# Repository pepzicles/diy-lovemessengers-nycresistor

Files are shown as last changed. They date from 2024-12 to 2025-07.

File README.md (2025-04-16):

# 💖 Welcome to our Love Messengers Page, NYC Resistor edition

demo

by Julia Daser and Pepi Ng
<br>
<br>
👯‍♀️ This workshop is a community effort - thank you to all the lovely people that have supported the project, 
participated in our workshops, provided valuable feedback, and helped host us. 
<br>
<br>
🥰 Special thanks go out to Kari Love, Woody and NYC Resistor, Jonah and Katherine and Siggraph, Grace Park and Aiyo Cheboi!
<br>

## Access all of your workshop materials here:
### [December 2024 Workshop](./Dec%202024)
### [February 2025 Workshop](./Feb%202025)

<br>

## Contact us
We hope you guys had tons of fun building  DIY Love Messengers<br>
If you run into any issues, please reach out to us!! We would love to help
<br>
#### Email:  yiqing.ng@gmail.com
#### Instagram: [@julia.daser](https://www.instagram.com/julia.daser/)
#### Youtube: [@WormiCollective](https://www.youtube.com/@WormiCollective)

<br>

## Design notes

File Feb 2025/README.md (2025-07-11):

# February 2025 Edition of NYC Resistor Workshop!
**Sunday, Feb 9th and 14th, 2025** 
## About 
Our DIY Love Messengers are the perfect gift for your friends/ partners, especially long-distance ones! When the button of one love messenger is pressed, both of them will light up - no matter HOW FAR AWAY the two messengers are! We will be using all the files, code and 3D models from this repository.
<br>
<br>
demo
<br>
<br>
<br>
by Julia Daser and Pepi Ng
<br>
<br>
Thank you Aiyo Cheboi for your help in prep work 💖
Thank you Grace Park for the graphic design 💖
<br>

## This Github Page Contains
1. [**3D models**](./3D%20Models) of the box encasing, the floor, and the hearts for 3D-printing
2. The [**Code**](./code.ino) for the ESP8266 Microcontrollers
3. The [**Class-Slides**](https://docs.google.com/presentation/d/1ocXh6diw_edAS3Q-rFSFNbqER26dfUnC6ZojbTQyBRY/edit?usp=sharing)
4. The Slides on [**How to Create a Database**](https://docs.google.com/presentation/d/19Xh5I5hXMwRNAT6mXwnOo7upIBXxUXw2HIQn1awf7jE/edit?usp=sharing)
5. The Slides on [**How to Upload the ESP8266 Code**](https://docs.google.com/presentation/d/1gHVXxIc9Vdh47K_fa2g4CjRUR9ceTofEAE9G6XgcR_w/edit?usp=sharing)

<br>

## You attended our  workshop and want to use the Love Messengers at home?
To use the *Love Messengers* at home, you need to re-upload the code with your own WiFi name and Password. 
Follow our instructions if you need a reminder on how to do so: [Instructions](https://docs.google.com/presentation/d/1gHVXxIc9Vdh47K_fa2g4CjRUR9ceTofEAE9G6XgcR_w/edit?usp=sharing)
<br>
<br>
You can keep using the same Database we created in the workshop. (If you want to create a new Database, or you have not created one yet, follow [this tutorial](https://docs.google.com/presentation/d/19Xh5I5hXMwRNAT6mXwnOo7upIBXxUXw2HIQn1awf7jE/edit?usp=sharing).

<br>

## Contact us
We hope you guys had tons of fun building  DIY Love Messengers 💙🧡  <br>
If you run into any issues, please reach out to us!! We would love to help
<br>
#### Email:  yiqing.ng@gmail.com
#### Instagram: [@julia.daser](https://www.instagram.com/julia.daser/)
#### Youtube: [@WormiCollective](https://www.youtube.com/@WormiCollective)

<br>
<br>

## Materials needed to build two Love Messengers
1. 4x 3D-printed translucent heart **halves** (see '3D models' folder)
2. 2x 3D-printed box encasings (see '3D models' folder)
3. 2x 3D-printed box floors (see '3D models' folder)
4. 2x [16mm pre-soldered illuminated push buttons](https://www.aliexpress.us/item/3256807351535133.html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) (Make sure to purchase 'momentary' and '4-pin' option) ($0.90 per)
5. 2x [pre-soldered LEDs](https://www.amazon.com/Assorted-Transparent-Warm-White-Emitting-Assortment/dp/B08G4VKN1W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) (Pre-soldered with resistors, different colors are available and all function the same) ($0.35 per)
6. 4x [M2.5 x 10 mm Screws](https://www.amazon.com/uxcell-100pcs-Stainless-Phillips-Tapping/dp/B01KXTUCM8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)
7. 2x [ESP32-WROOM-32 microcontrollers, unassembled.](https://www.amazon.com/dp/B0BHW1CNCM?smid=A2Z10KY0342329&ref_=chk_typ_imgToDp&th=1) (We used ones with USBC ports.) ($3.30 per)
8. 2x [USBC wires](https://www.amazon.com/dp/B0CFQ5T5F6?ref=ppx_yo2ov_dt_b_fed_asin_title&th=1) (To upload code to microcontrollers, your USB wire needs to be able to both *charge* and *transmit data*.) ($2.00 per)

<br>   
<br>

## Wire Diagram: 
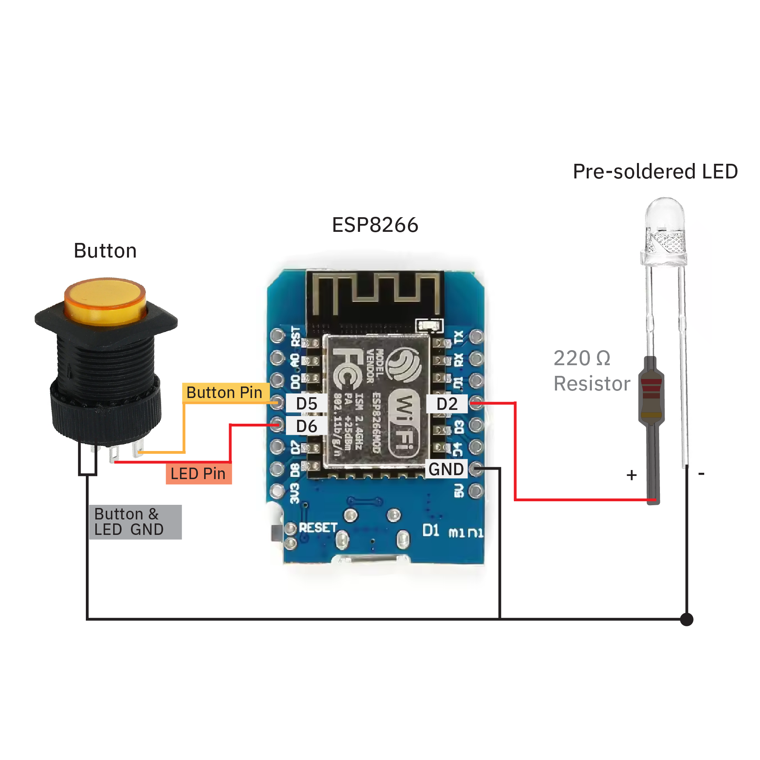
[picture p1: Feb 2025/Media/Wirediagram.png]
demo


<br>   
<br>

## Other Tools/ Equipment: 
1. Pliers
2. Wire Stripper
3. Small Screwdrivers
4. Soldering Kit

<br>
<br>

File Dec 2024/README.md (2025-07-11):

# December 2024 Edition NYC Resistor Workshop!
**Saturday, Dec 21, 2024** 
<br>
by Julia Daser and Pepi Ng
<br>

## This Github Page Contains
1. [**3D models**](./3D%20Models) of the box encasing, the floor, and the hearts for 3D-printing
2. The [**Code**](./code.ino) for the ESP32 Microcontrollers
3. The [**Class-Slides**](https://docs.google.com/presentation/d/1tKyRhq-H0f7qh0r20IBgMoWx7r3AGBdcS3LCC1Dzuw8/edit?usp=sharing)
4. The Slides on [**How to Create a Database**](https://docs.google.com/presentation/d/19Xh5I5hXMwRNAT6mXwnOo7upIBXxUXw2HIQn1awf7jE/edit?usp=sharing)
5. The Slides on [**How to Upload the ESP32 Code**](https://docs.google.com/presentation/d/10jpJMJF2ff4qg-6BC0tEkhLmOqasLfKd7yKnnkN3o50/edit?usp=sharing)

<br>

## You attended our  workshop and want to use the Love Messengers at home?
To use the *Love Messengers* at home, you need to re-upload the code with your own WiFi name and Password. 
Follow our PDF-instructions if you need a reminder on how to do so: [PDF Instructions](ADD URL HERE)
<br>
<br>
You can keep using the same Database we created in the workshop. (If you want to create a new Database, or you have not created one yet, follow [this tutorial](https://docs.google.com/presentation/d/19Xh5I5hXMwRNAT6mXwnOo7upIBXxUXw2HIQn1awf7jE/edit?usp=sharing).

<br>

## Contact us
We hope you guys had tons of fun building  DIY Love Messengers 💙🧡  <br>
If you run into any issues, please reach out to us!! We would love to help
<br>
#### Email:  yiqing.ng@gmail.com
#### Instagram: [@julia.daser](https://www.instagram.com/julia.daser/)
#### Youtube: [@WormiCollective](https://www.youtube.com/@WormiCollective)

<br>

## About 
Our DIY Love Messengers are the perfect gift for your friends/ partners, especially long-distance ones! When the button of one love messenger is pressed, both of them will light up - no matter HOW FAR AWAY the two messengers are! We will be using all the files, code and 3D models from this repository.
<br>
<br>
demo
<br>
<br>

## Materials needed to build two Love Messengers
1. 4x 3D-printed translucent heart OR star **halves** (see '3D models' folder)
2. 2x 3D-printed box encasings (see '3D models' folder)
3. 2x 3D-printed box floors (see '3D models' folder)
4. 2x [16mm pre-soldered illuminated push buttons](https://www.amazon.com/Momentary-Button-Switch-Assorted-Self-Resetting/dp/B08SKJ6V7Z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) ($0.62 per)
5. 2x [pre-soldered Super bright LEDs](https://www.amazon.com/dp/B01AUI4VQU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) (Pre-soldered with resistors) ($5.99 for 100)
6. 4x [M2.5 x 10 mm Screws](https://www.amazon.com/uxcell-100pcs-Stainless-Phillips-Tapping/dp/B01KXTUCM8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)
7. 2x [ESP32-WROOM-32 microcontrollers, unassembled. We used ones with USBC ports.](https://www.amazon.com/dp/B0B18NK2MS?ref=ppx_yo2ov_dt_b_fed_asin_title&th=1) ($5.40 per)
8. 2x [USBC wires](https://www.amazon.com/dp/B0CFQ5T5F6?ref=ppx_yo2ov_dt_b_fed_asin_title) (To upload code to microcontrollers, your USB wire needs to be able to both *charge* and *transmit data*.)

<br>   
<br>

## Wire Diagram: 
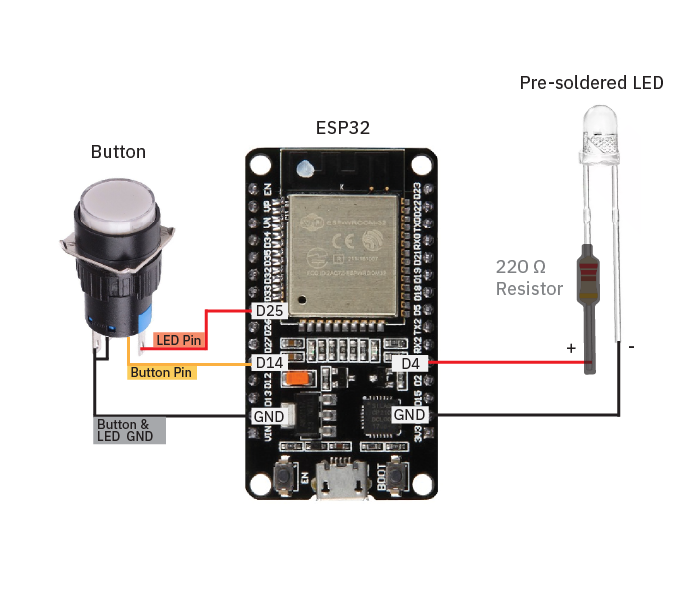
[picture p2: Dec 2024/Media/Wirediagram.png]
demo


<br>   
<br>

## Other Tools/ Equipment: 
1. Pliers
2. Wire Stripper
3. Small Screwdrivers
4. Soldering Kit

<br>
<br>

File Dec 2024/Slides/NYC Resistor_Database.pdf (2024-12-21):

## Creating the Real Time Database

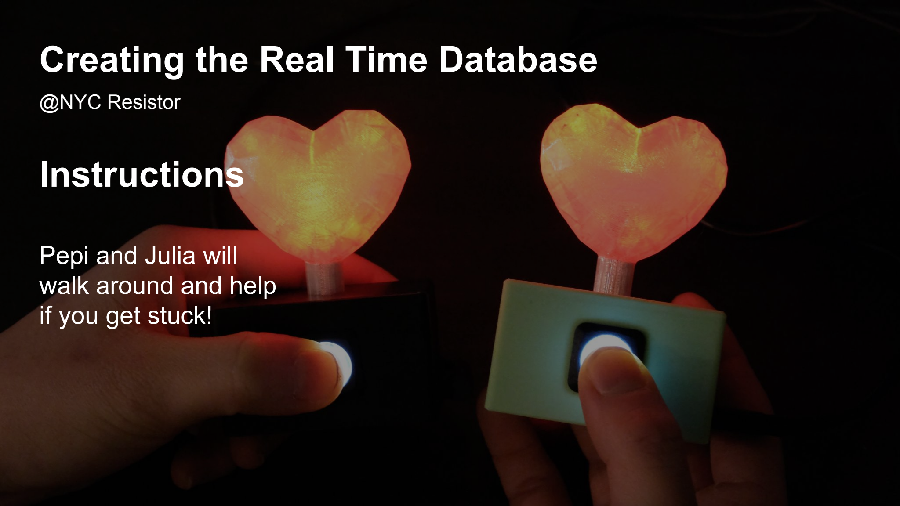
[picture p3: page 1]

@NYC Resistor

Pepi and Julia will
walk around and help
if you get stuck!

## Instructions

Step 1: Open console.firebase.google.com in Google Chrome, and log into your personal Google account.

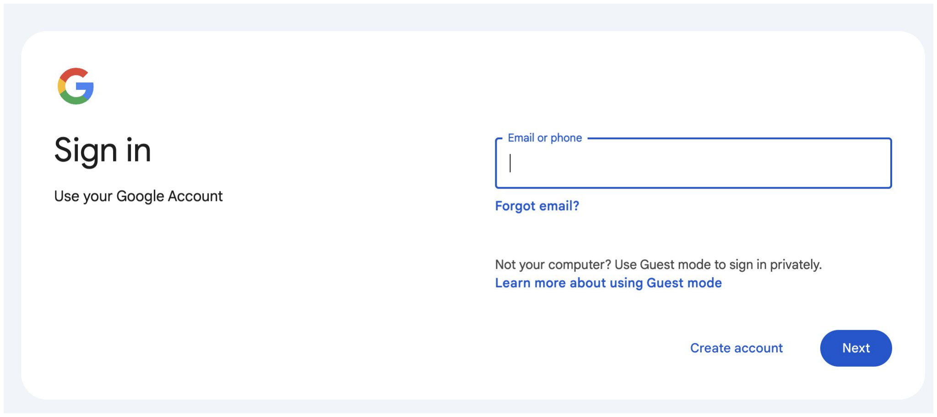
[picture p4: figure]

Step 2: In the Firebase website, select ”Get started with a Firebase project”

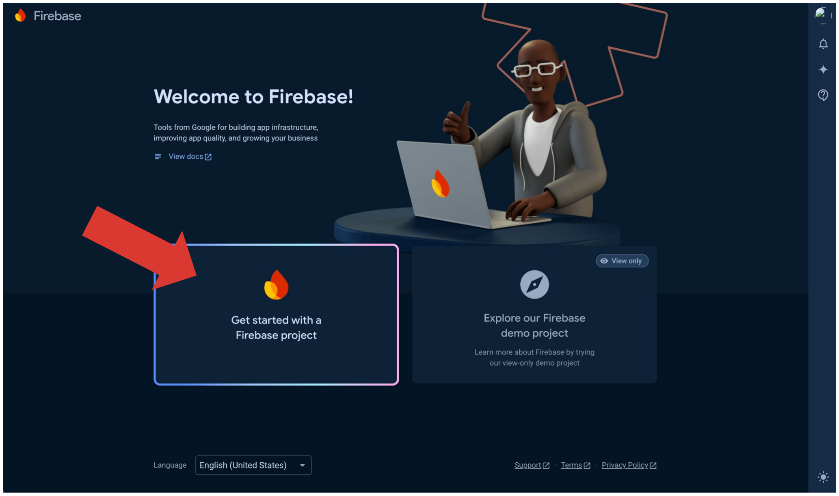
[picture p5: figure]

Step 3: Give your project a name, and hit the “Continue” button.

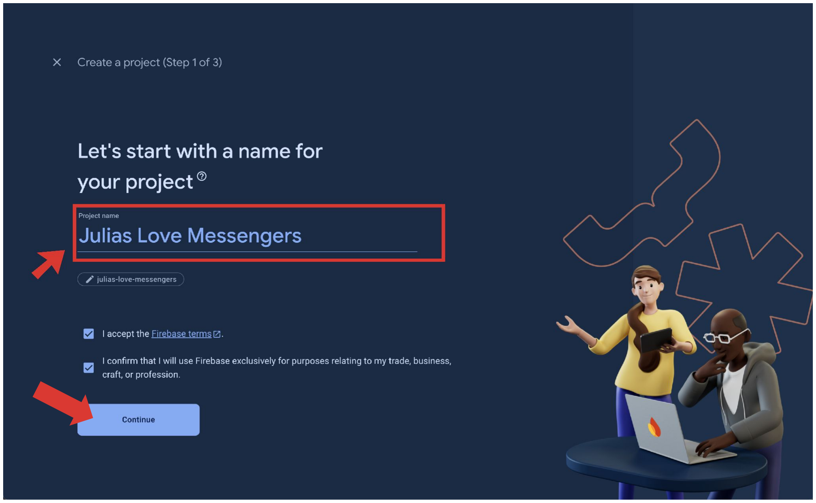
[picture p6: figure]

Step 4: Disable Google Analytics in the slider at the bottom of the page, then hit “Create Project”.

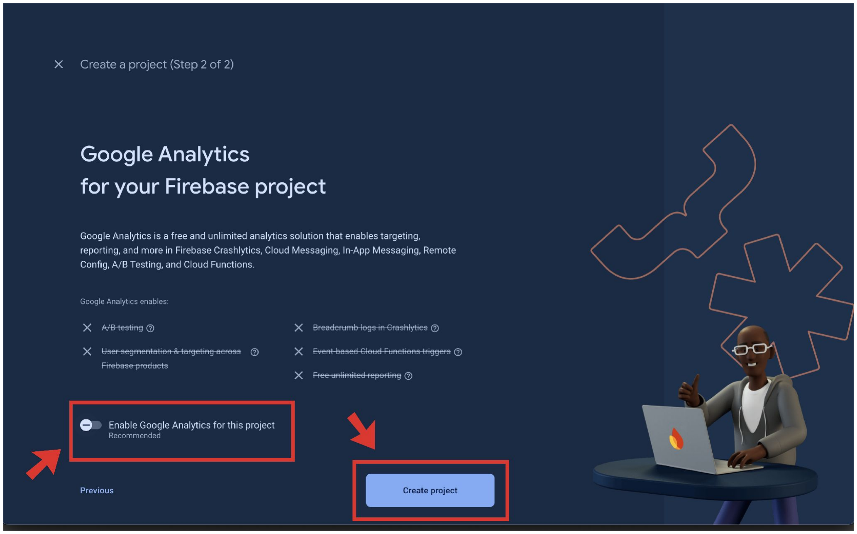
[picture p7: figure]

Step 5: Once the project has loaded, hit the “Continue” button.

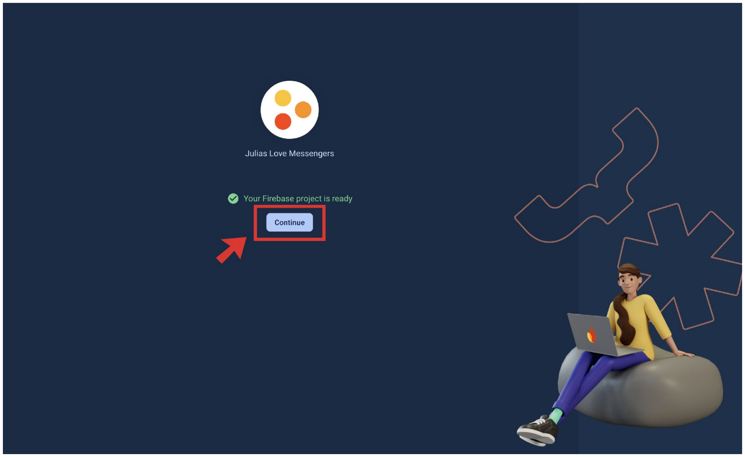
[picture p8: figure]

Step 6: We are now in the project console page! On the left panel bar, enter the “Build” menu, and select “Authentication”.

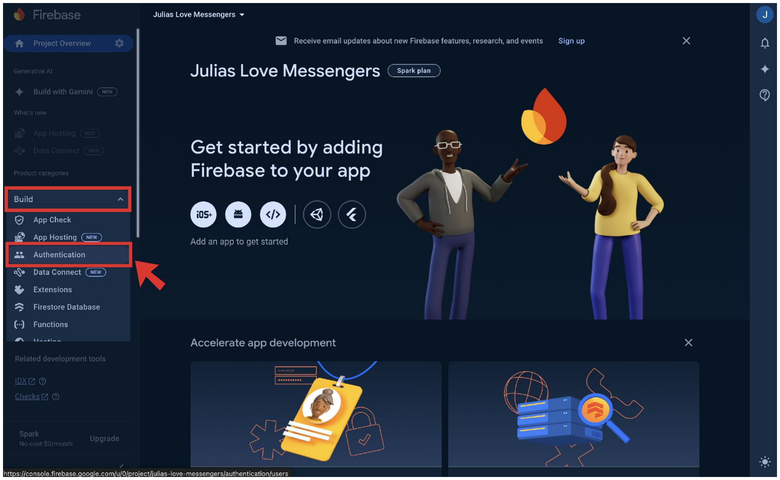
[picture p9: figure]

Step 7: In the authentication page, select “Get started”.

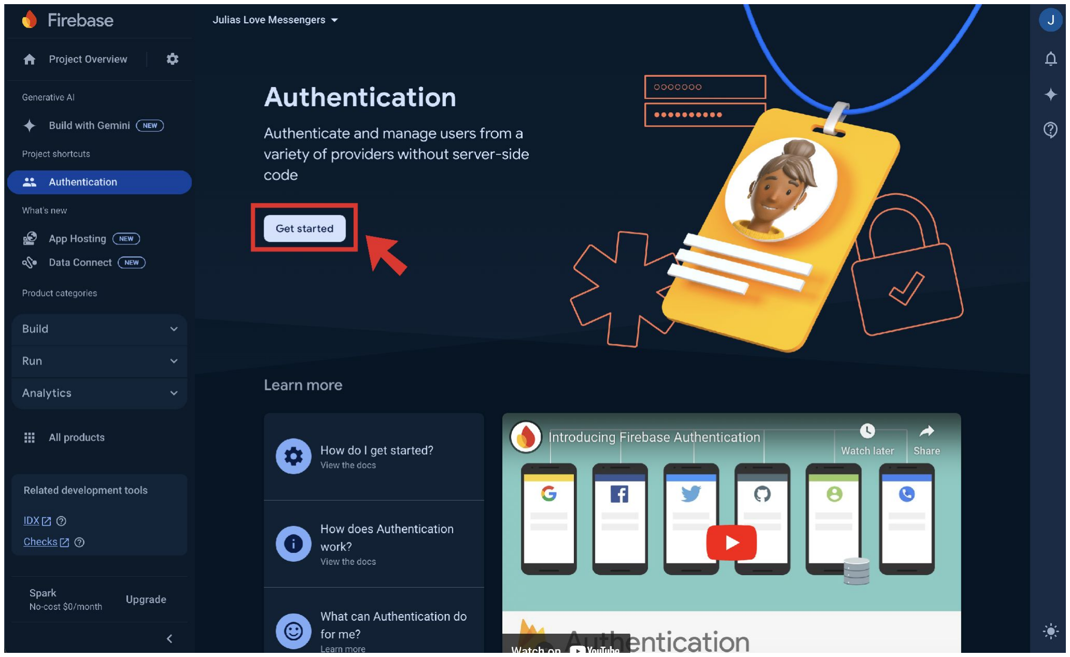
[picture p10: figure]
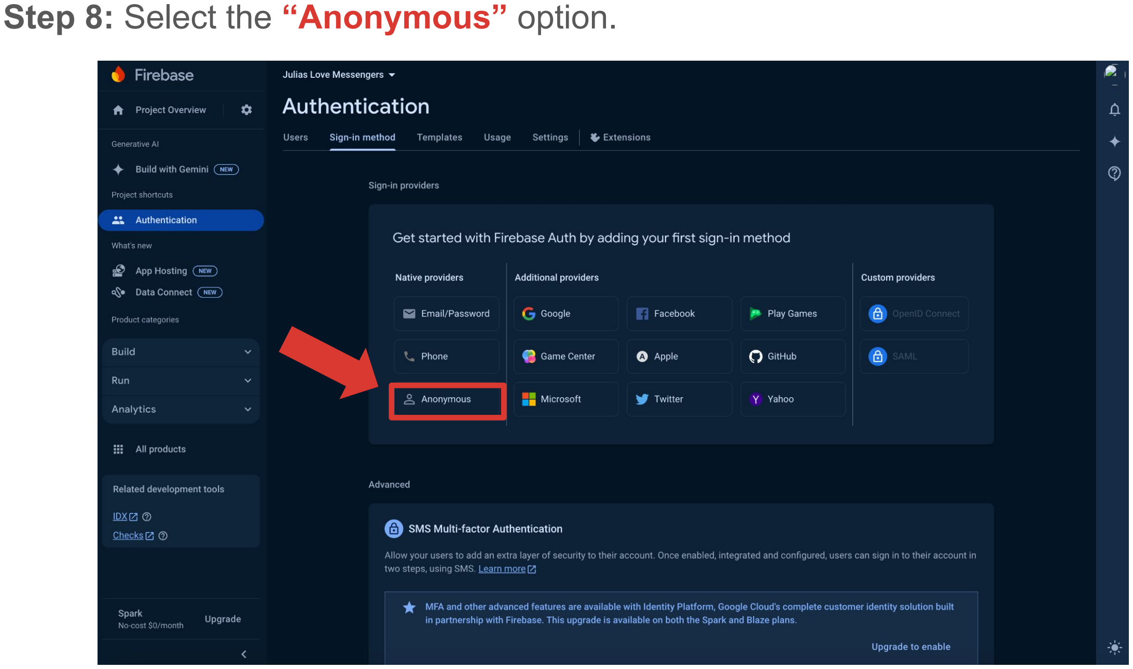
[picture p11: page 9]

Step 8: Select the “Anonymous” option.

Step 9: Toggle the “Enable” slider, and hit the “Save” button.

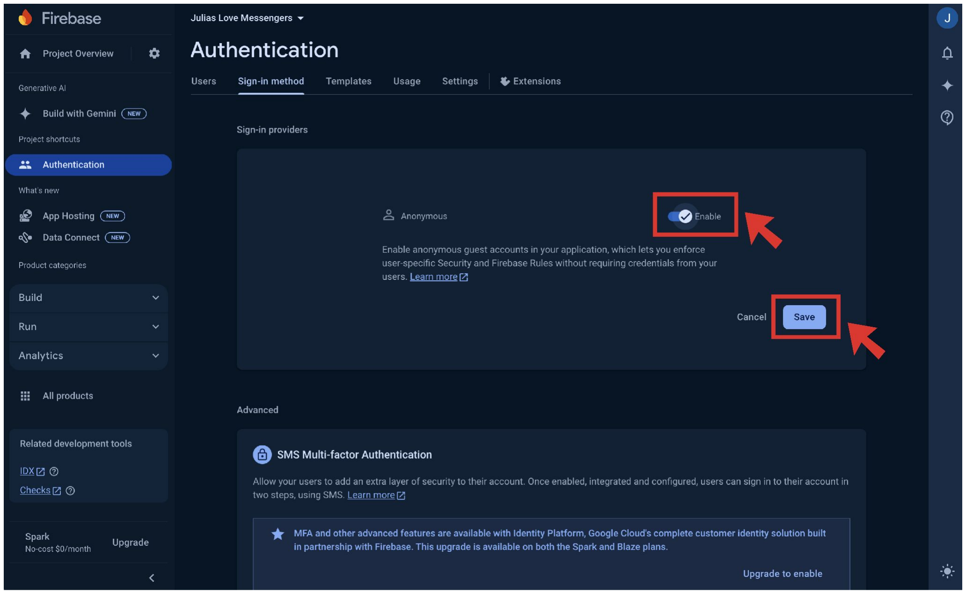
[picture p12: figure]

Step 10: Now we will build the database! Go to the left panel bar. In the “Build” menu, select “Realtime Database”

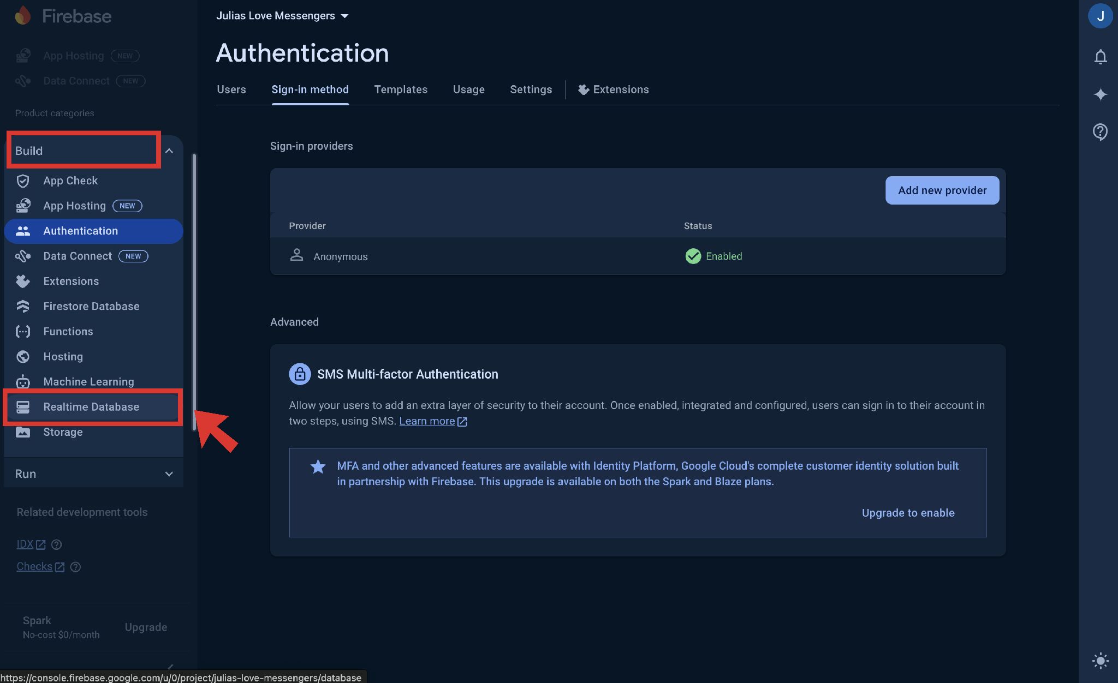
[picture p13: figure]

Step 11: Select “Create Database”

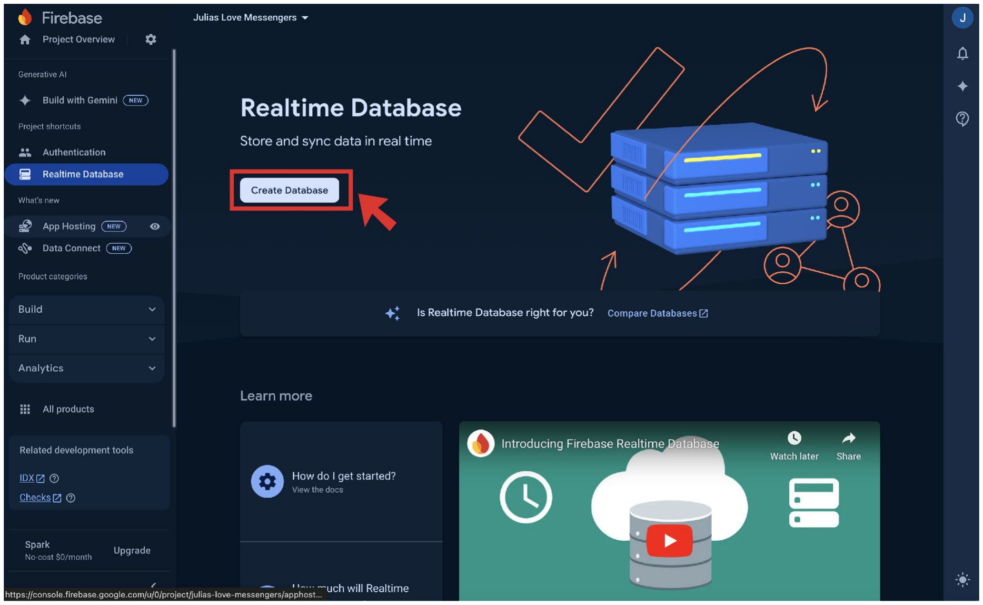
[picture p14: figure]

Step 12: Keep the Realtime Database location as “United States”, and hit “Next”

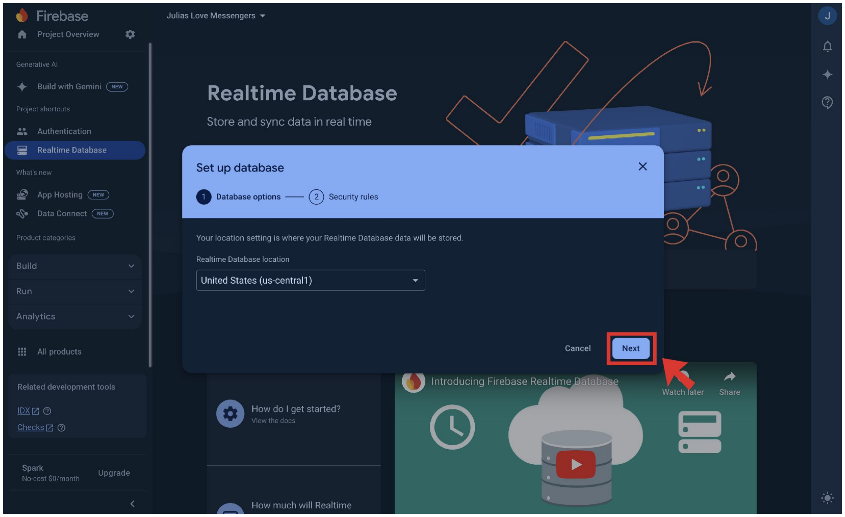
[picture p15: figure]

Step 13: Select “Start in test mode”, and hit “Enable”

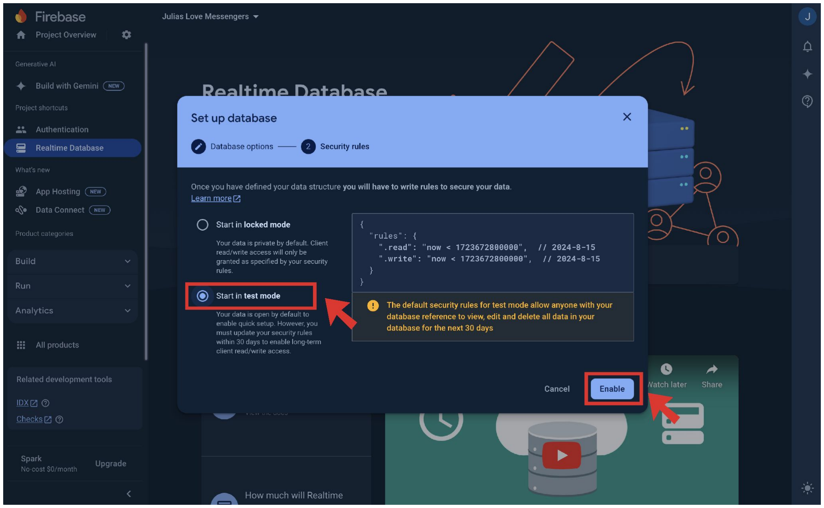
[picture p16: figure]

Step 14: YEYY! This is our Real Time Database . It currently has no data stored, but as soon as we connect the Love Messengers, it will populate with information.

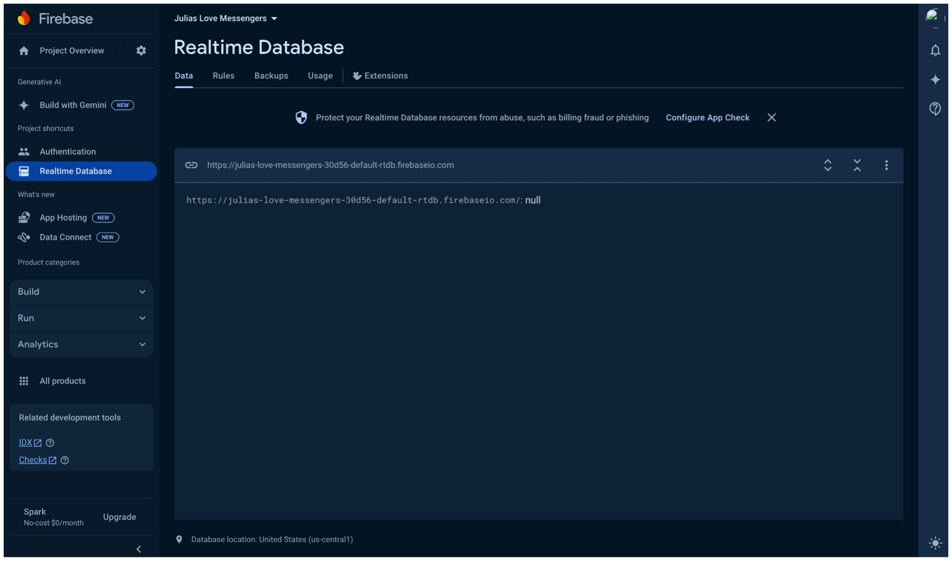
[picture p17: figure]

Step 15: Select the “Rules” navigation point.

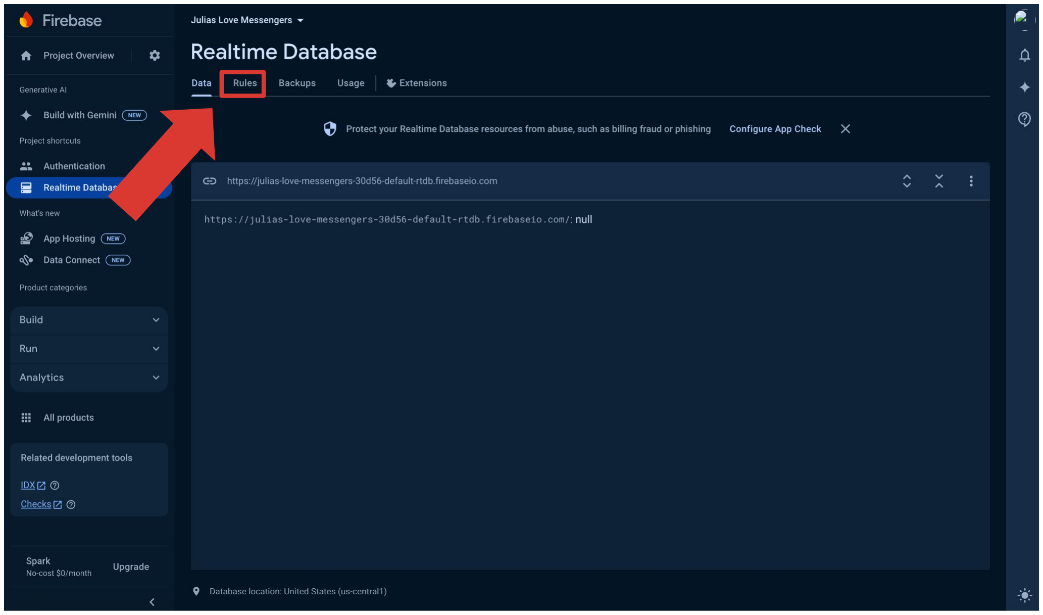
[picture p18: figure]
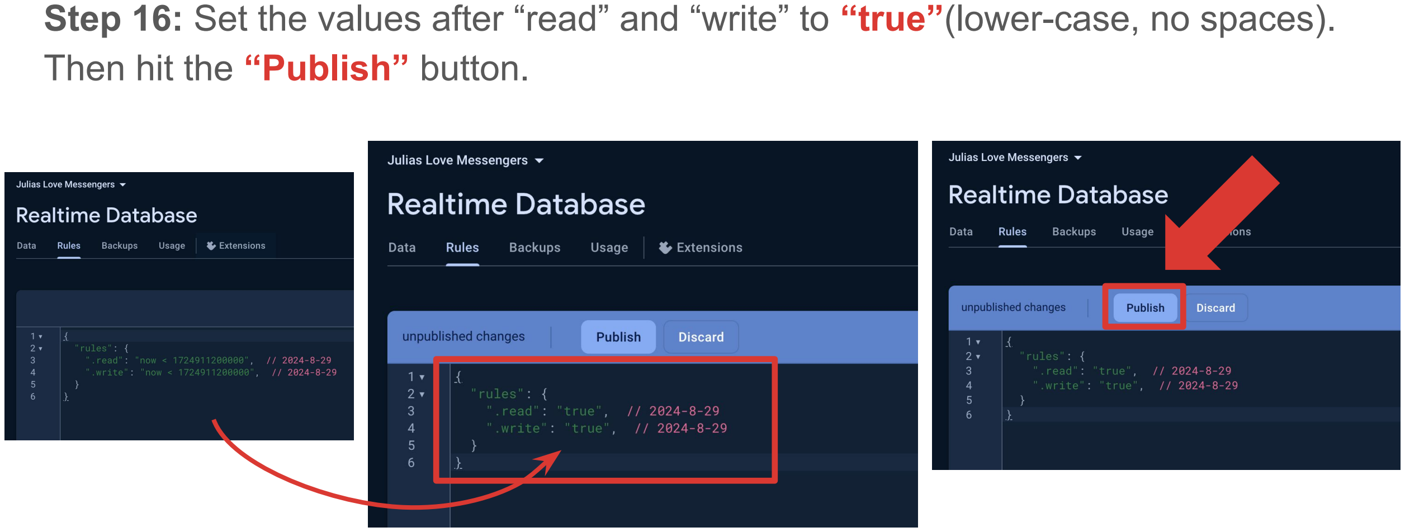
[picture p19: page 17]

Step 16: Set the values after “read” and “write” to “true”(lower-case, no spaces). Then hit the “Publish” button.

All done! Keep the Firebase window open for now, because we will need it later in the code. We will regroup when everyone is done.

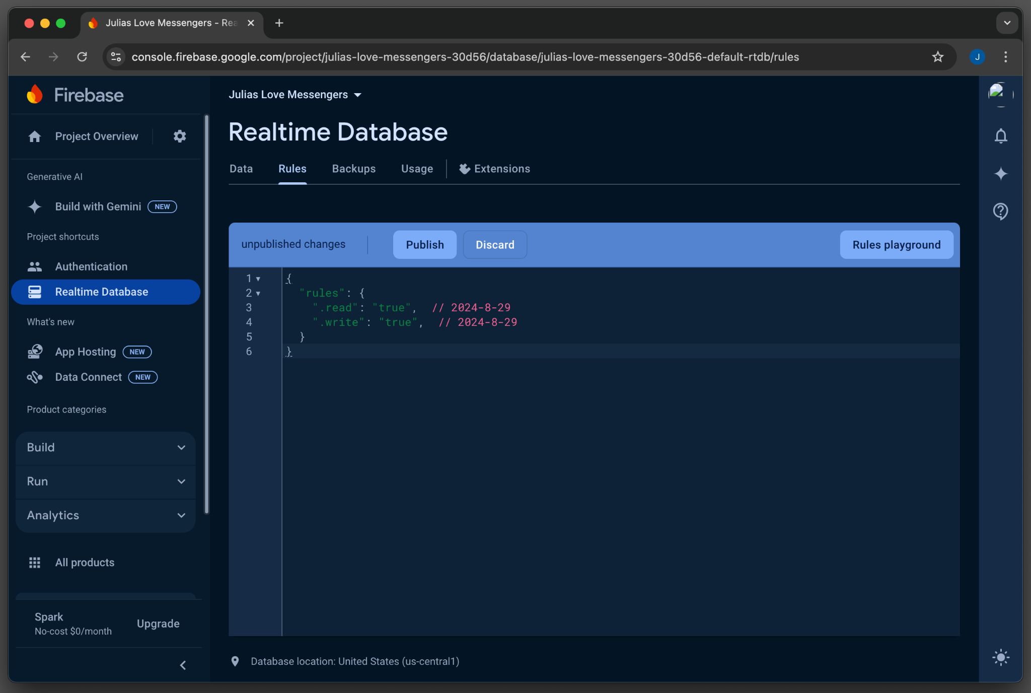
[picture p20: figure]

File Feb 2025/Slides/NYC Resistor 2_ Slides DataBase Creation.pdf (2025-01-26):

## Creating the Real Time Database


@NYC Resistor

Pepi and Julia will
walk around and help
if you get stuck!

## Instructions

Step 1: Open console.firebase.google.com in Google Chrome, and log into your personal Google account.

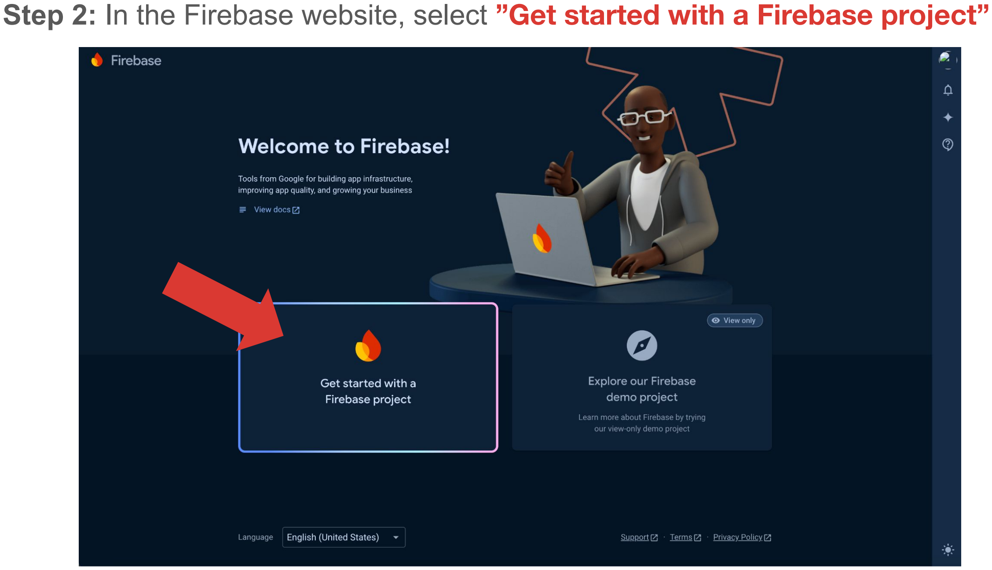
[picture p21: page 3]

Step 2: In the Firebase website, select ”Get started with a Firebase project”

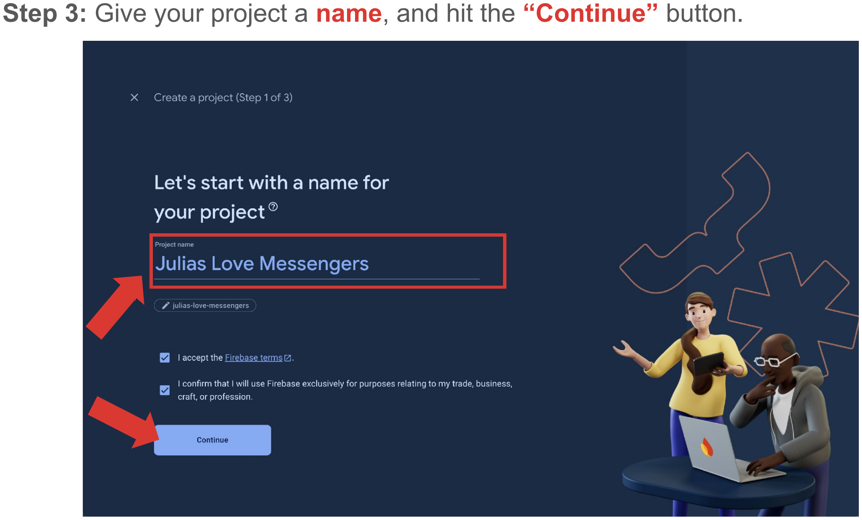
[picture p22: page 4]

Step 3: Give your project a name, and hit the “Continue” button.

Step 4: Disable Google Analytics in the slider at the bottom of the page, then hit “Create Project”.

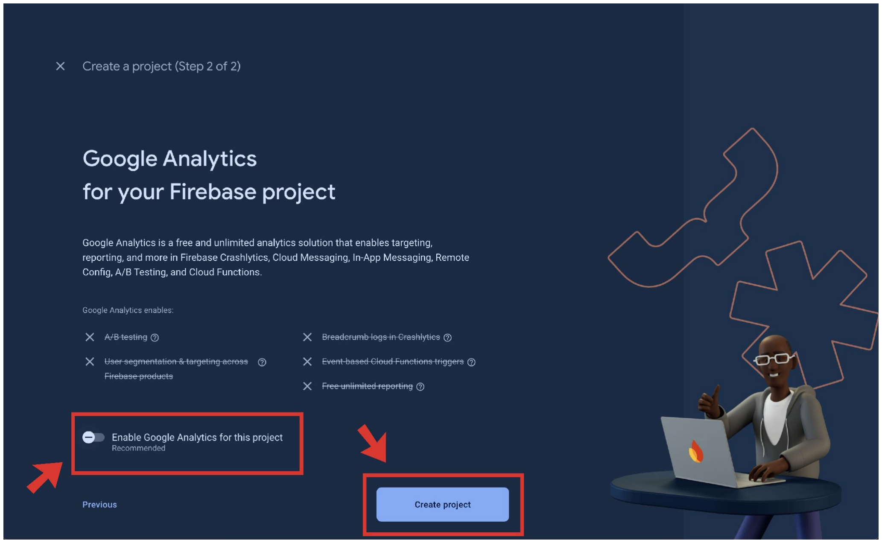
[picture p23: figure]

Step 5: Once the project has loaded, hit the “Continue” button.

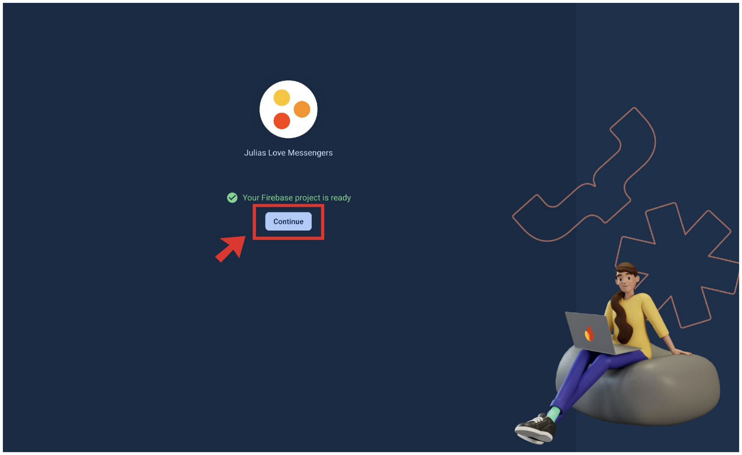
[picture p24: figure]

Step 6: We are now in the project console page! On the left panel bar, enter the “Build” menu, and select “Authentication”.


Step 7: In the authentication page, select “Get started”.


Step 8: Select the “Anonymous” option.


Step 9: Toggle the “Enable” slider, and hit the “Save” button.

Step 10: Now we will build the database! Go to the left panel bar. In the “Build” menu, select “Realtime Database”


Step 11: Select “Create Database”


Step 12: Keep the Realtime Database location as “United States”, and hit “Next”


Step 13: Select “Start in test mode”, and hit “Enable”

Step 14: YEYY! This is our Real Time Database . It currently has no data stored, but as soon as we connect the Love Messengers, it will populate with information.


Step 15: Select the “Rules” navigation point.

Step 16: Remove both “now < 172491120000” texts, and replace them with “true” like in the screenshots below.


This is how your page should look in the end

Step 17: “Publish” the changes.


All done! Keep the Firebase window open for now, because we will need it later in the code. We will regroup when everyone is done.


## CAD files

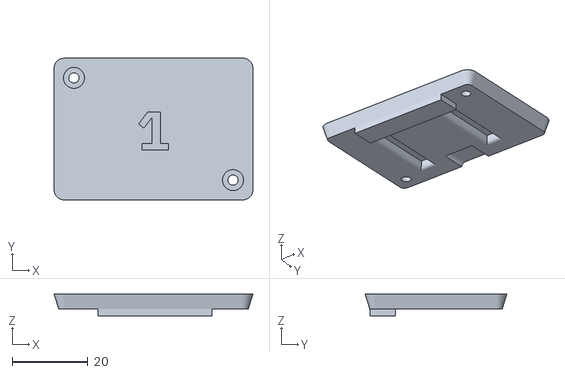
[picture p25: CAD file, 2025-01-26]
Feb 2025/3D Models/floor_user1.stl
52.5 x 37.5 x 5.76

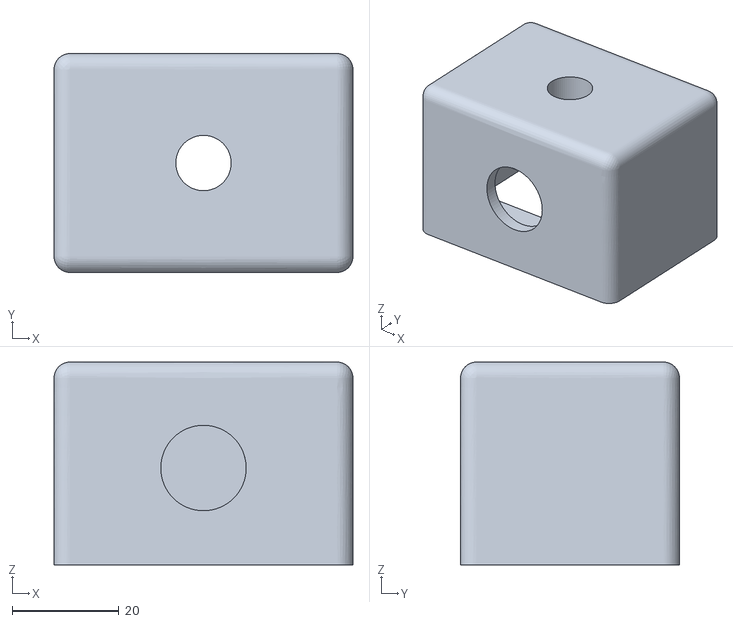
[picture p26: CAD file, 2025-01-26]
Feb 2025/3D Models/box.stl
56.0 x 41.0 x 38.0

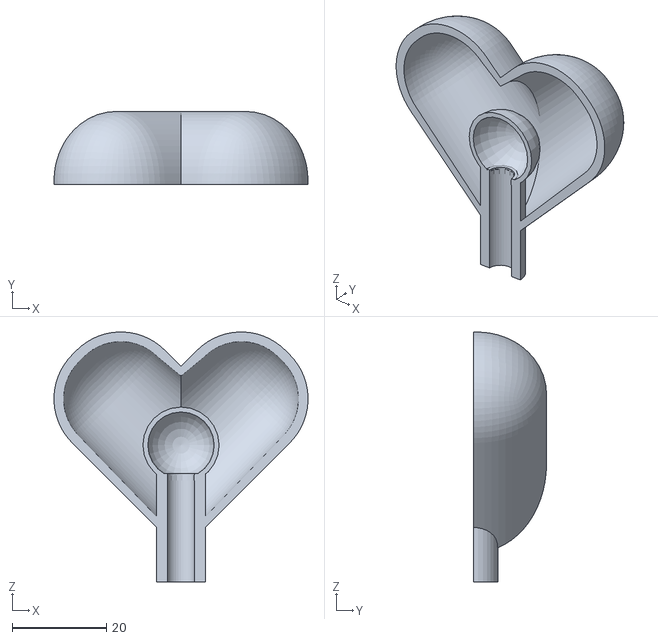
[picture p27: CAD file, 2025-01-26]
Feb 2025/3D Models/heart_half.stl
54.0 x 15.5 x 53.1

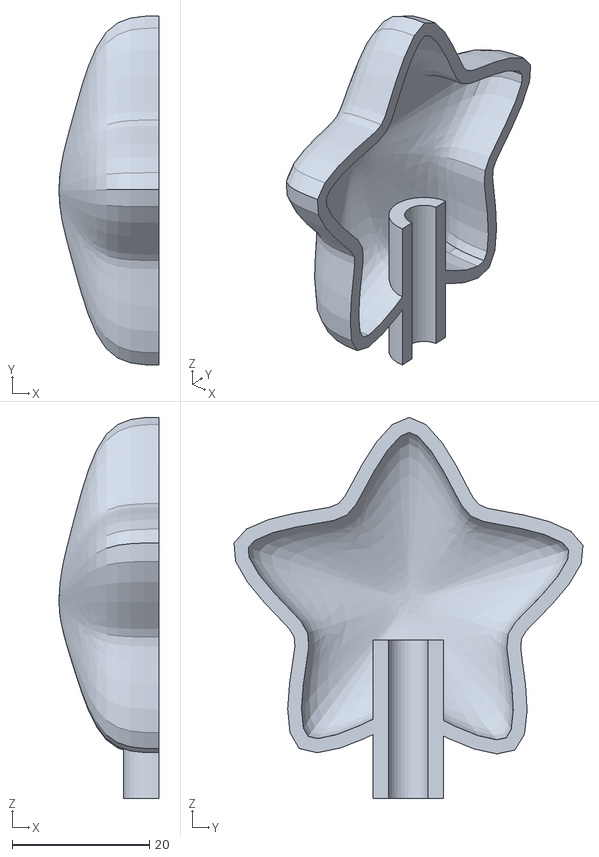
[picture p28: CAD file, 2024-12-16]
Dec 2024/3D Models/star_half.stl
14.6 x 50.8 x 55.5

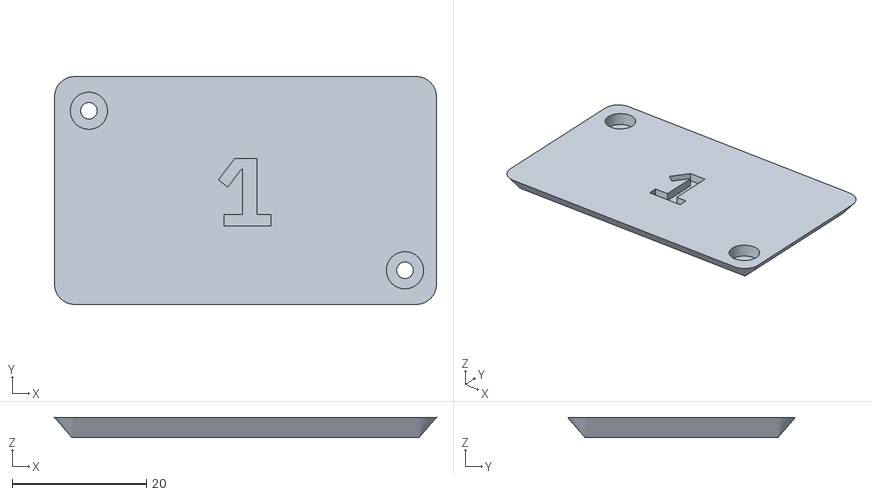
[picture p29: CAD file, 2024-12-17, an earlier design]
Dec 2024/3D Models/floor_user1.stl
57.0 x 34.0 x 3.00

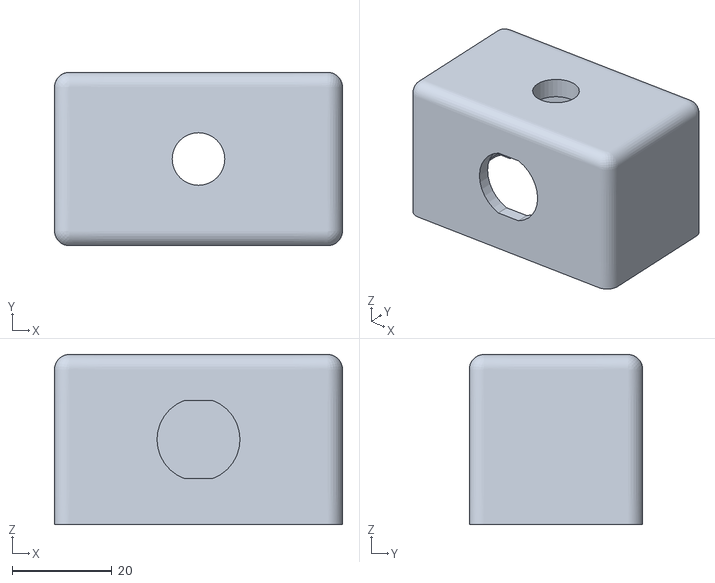
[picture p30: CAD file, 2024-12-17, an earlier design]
Dec 2024/3D Models/box.stl
57.8 x 34.8 x 34.1

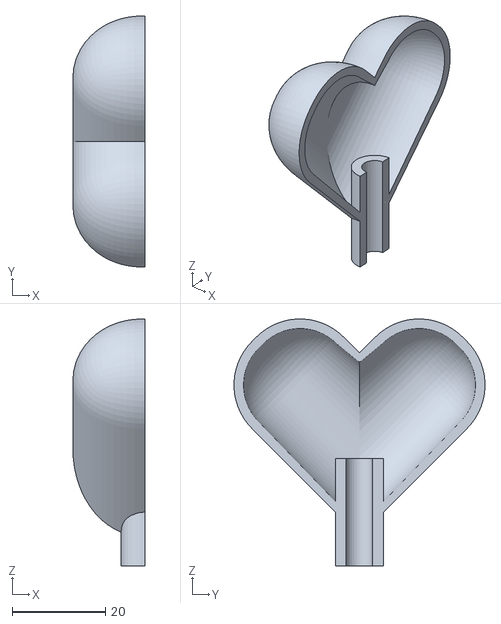
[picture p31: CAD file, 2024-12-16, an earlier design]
Dec 2024/3D Models/heart_half.stl
15.5 x 54.0 x 53.1

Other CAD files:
Feb 2025/3D Models/floor_user2.stl
Dec 2024/3D Models/floor_user2.stl

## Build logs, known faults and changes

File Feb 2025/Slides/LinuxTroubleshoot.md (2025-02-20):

# Arduino IDE not detecting port

**Contributed by Rhea Malviya ([@rheam97](https://github.com/rheam97)) who attended our workshop @ NYC Resistor on 14 Feb!**

Many Linux distros come with a BRLTTY application that allows people hard-of-sight to access the computer's text-based console through a braille display. These displays use a serial port to communicate with the computer, but it takes over all general purpose USB ports. This causes the port to not appear in the Arduino IDE ports list. You can read more [**here**](https://github.com/arduino/help-center-content/issues/155).

You can simply uninstall BRLTTY, but if people find the application useful, this [**link**](https://unix.stackexchange.com/questions/670636/unable-to-use-usb-dongle-based-on-usb-serial-converter-chip/670637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) shares a more in-depth approach.

```
sudo apt-get remove brltty
```
I restarted my computer after doing this and the Ports link in Arduino was no longer greyed out. 

# Arduino IDE not given permission for port access to compile

A temporary testing solution is to give read, write, and execute access to the port with this command:

```
sudo chmod a+rw /dev/ttyUSB0 
```

However a more permanent solution is to add yourself to the dialout group for full and direct access to serial ports. You can read more [**here**](https://support.arduino.cc/hc/en-us/articles/360016495679-Fix-port-access-on-Linux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,Add%20yourself%20to%20the%20dialout%20group,communicate%20on%20the%20serial%20ports.).

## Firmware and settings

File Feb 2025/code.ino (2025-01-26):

// Importing libraries
#include <ESP8266WiFi.h>
#include <Firebase_ESP_Client.h>

// Firebase requires these helpers
#include "addons/TokenHelper.h"
#include "addons/RTDBHelper.h"

// Wi-Fi credentials
#define WIFI_SSID "insert Wifi Name here"
#define WIFI_PASSWORD "insert Wifi Password here"

// Firebase credentials
#define API_KEY "insert API Key here"
#define DATABASE_URL "insert API Url here"

// Hardware components (LED & button)
const int ledPin = D2; 
const int buttonPin = D5;
const int buttonLedPin = D6;

// Global variables
bool firebaseData = false;
int buttonState = 1;

// Define Firebase Data object and other necessary objects
FirebaseData fbdo;
FirebaseAuth auth;
FirebaseConfig config;
unsigned long lastFirebaseUpdate = 0;
int count = 0;
bool signupOK = false;

void setup() {
  Serial.begin(115200);

  pinMode(ledPin, OUTPUT);
  pinMode(buttonPin, INPUT_PULLUP);
  pinMode(buttonLedPin, OUTPUT);

  connectWiFi();
  connectFirebase();
  digitalWrite(buttonLedPin, HIGH);
}

void loop() {
  if (Firebase.ready() && signupOK && (millis() - lastFirebaseUpdate > 1000)) {  // Avoid overwhelming the database
    lastFirebaseUpdate = millis();

    buttonState = digitalRead(buttonPin);
    Serial.println(buttonState);
    uploadData(buttonState);
    downloadData();
    manageLED(buttonState, firebaseData);
  }
  delay(5);
}

void connectWiFi() {
  WiFi.begin(WIFI_SSID, WIFI_PASSWORD);
  Serial.println("Connecting to Wi-Fi...");
  while (WiFi.status() != WL_CONNECTED) {
    digitalWrite(buttonLedPin, HIGH);
    delay(500);
    digitalWrite(buttonLedPin, LOW);
    delay(500);
    Serial.print(".");
  }
  Serial.println("\nConnected with IP: ");
  Serial.println(WiFi.localIP());
}

void connectFirebase() {
  config.api_key = API_KEY;
  config.database_url = DATABASE_URL;

  if (Firebase.signUp(&config, &auth, "", "")) {
    Serial.println("Firebase initialized successfully");
    signupOK = true;
  } else {
    Serial.printf("Firebase signup error: %s\n", config.signer.signupError.message.c_str());
  }

  config.token_status_callback = tokenStatusCallback;
  Firebase.begin(&config, &auth);
  Firebase.reconnectWiFi(true);
}

void uploadData(int buttonstate) {
  if (Firebase.RTDB.setInt(&fbdo, "/user_1", buttonstate)) {
    Serial.println("Data UPLOAD successful");
  } else {
    Serial.printf("Data UPLOAD failed: %s\n", fbdo.errorReason().c_str());
  }
}

void downloadData() {
  if (Firebase.RTDB.getInt(&fbdo, "/user_2")) {
    firebaseData = fbdo.intData();
    Serial.println("Data DOWNLOAD successful");
  } else {
    Serial.printf("Data DOWNLOAD failed: %s\n", fbdo.errorReason().c_str());
  }
}

void manageLED(int buttonState, int firebaseData) {
  if (buttonState == LOW || firebaseData == LOW) {
    digitalWrite(ledPin, HIGH);
    delay(1000);
    digitalWrite(ledPin, LOW);
  } else {
    digitalWrite(ledPin, LOW);
  }
}

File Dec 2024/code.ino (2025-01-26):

// Importing libraries
#include <WiFi.h>
#include <Firebase_ESP_Client.h>
#include "addons/TokenHelper.h"
#include "addons/RTDBHelper.h"

// Wi-Fi credentials
#define WIFI_SSID "NYCR24"
#define WIFI_PASSWORD "clubmate"

// Firebase credentials
#define API_KEY "insert API Key here"
#define DATABASE_URL "insert API Url here"

// LED & button connections to the ESP
const int ledPin = 4;
const int buttonPin = 14;
const int buttonLedPin = 25;

// Define Firebase Data object and other necessary objects
bool firebaseData = false;
int buttonState = 1;
FirebaseData fbdo;
FirebaseAuth auth;
FirebaseConfig config;
unsigned long lastFirebaseUpdate = 0;
int count = 0;
bool signupOK = false;

void setup() {
  Serial.begin(115200);

  pinMode(ledPin, OUTPUT);
  pinMode(buttonPin, INPUT_PULLUP);
  pinMode(buttonLedPin, OUTPUT);

  connectWiFi();
  connectFirebase();
  digitalWrite(buttonLedPin, HIGH);
}

void loop() {
  if (Firebase.ready() && signupOK && (millis() - lastFirebaseUpdate > 1000)) {  // timer
    lastFirebaseUpdate = millis();

    buttonState = digitalRead(buttonPin); //checking if our button is pressed
    uploadData(buttonState);
    downloadData();
    manageLED(buttonState, firebaseData); // turning the LED on or off
  }
  delay(5);
}

void connectWiFi() {
  WiFi.begin(WIFI_SSID, WIFI_PASSWORD);
  Serial.print("Connecting to Wi-Fi");
  while (WiFi.status() != WL_CONNECTED) {
    Serial.println("Connecting to Wifi...");
    digitalWrite(buttonLedPin, HIGH);
    delay(500);
    digitalWrite(buttonLedPin, LOW);
    delay(500);
  }
  Serial.print("Connected with IP: ");
  Serial.println(WiFi.localIP());
}

void connectFirebase() {
  config.api_key = API_KEY;
  config.database_url = DATABASE_URL;

  if (Firebase.signUp(&config, &auth, "", "")) {
    Serial.println("Firebase successful");
    signupOK = true;
  } else {
    Serial.printf("Firebase error");
  }

  config.token_status_callback = tokenStatusCallback;
  Firebase.begin(&config, &auth);
  Firebase.reconnectWiFi(true);
}

void uploadData(int buttonstate) {
  if (Firebase.RTDB.setInt(&fbdo, "/user_1", buttonstate)) {
    Serial.printf("Data UPLOAD successful,  ");
  } else {
    Serial.println("Data UPLOAD failed,  ");
  }
}

void downloadData() {
  if (Firebase.RTDB.getInt(&fbdo, "/user_2")) {
    firebaseData = fbdo.intData();
    Serial.println("Data DOWNLOAD successful");
  } else {
    Serial.println("Data DOWNLOAD failed");
  }
}

void manageLED(int buttonState, int firebaseData) {
  if (buttonState == HIGH or firebaseData == HIGH) {
    digitalWrite(ledPin, HIGH); // turning on the LED
    delay(1000);
    digitalWrite(ledPin, LOW); // turning off the LED
  } else {
    digitalWrite(ledPin, LOW);
  }
}

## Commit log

2024-12-21 Rename NYC Resistor_ Slides DB.pdf to NYC Resistor_ Database.pdf
2025-01-27 Rename NYC Resistor 2_ Slides DB.pdf to NYC Resistor 2_ Slides DataBase.pdf
